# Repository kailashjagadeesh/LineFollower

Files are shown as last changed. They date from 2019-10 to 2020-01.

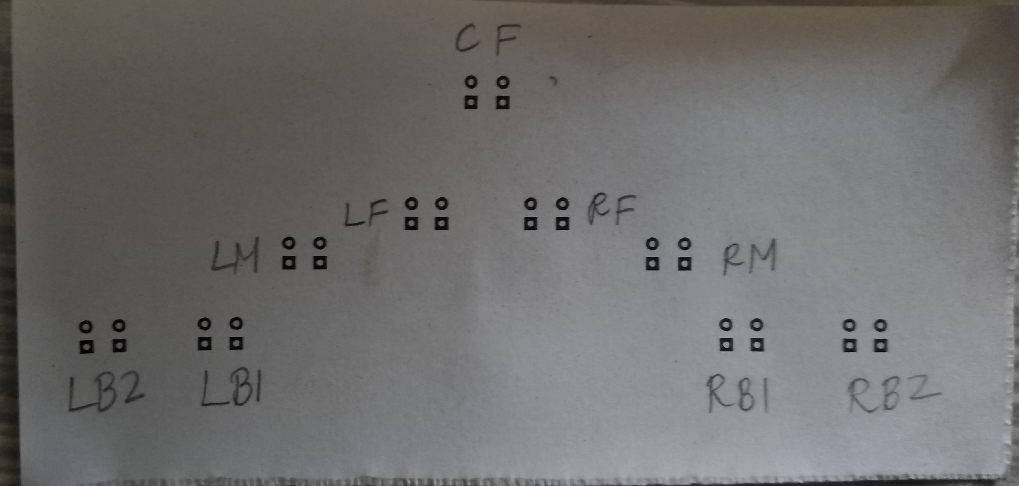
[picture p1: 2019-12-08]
Gen3/sensorNomenclature.jpg

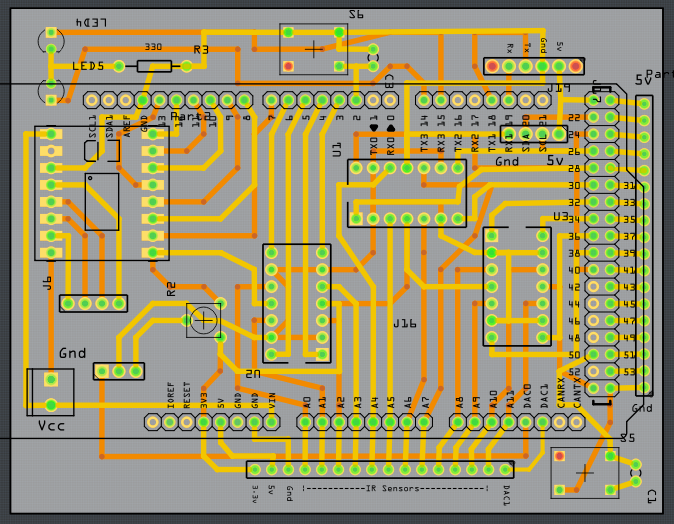
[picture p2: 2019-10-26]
Gen3/Designs/shieldPCB/PCB snip.png

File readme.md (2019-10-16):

# About
A general purpose differential-drive bot that can be used for various events.

# Code base tree
```
.
│── Gen1 : Meshmerize 2018 zonals, IITB TechFest
│   ├── actualrun
│   ├── Basic
│   │   ├── blackleft
│   │   ├── blackright
│   │   ├── whiteleft
│   │   └── whiteright
│   ├── calibration
│   ├── dryrun
│   ├── solving
│   ├── Today-Finals
│   ├── Track images
│   └── With EEPROM only
│       ├── BlackLeftEEPROM
│       ├── BlackRightEEPROM
│       ├── WhiteLeftEEPROM
│       └── WhiteRightEEPROM
├── Gen2 : Meshmerize 2019 zonals, IITB TechFest
│   ├── Meshmerizer
│   └── shortestPath
└── Gen3 : Meshmerize 2019 Finale, IITB TechFest
    └── Designs
        ├── sensorsPCB : 9 IR sensor PCB board with 3 control pins for controlling IR TX  
        └── shieldPCB
```

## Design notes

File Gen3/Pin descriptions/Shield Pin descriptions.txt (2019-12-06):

Motor Pins on MCU:

D12 - PWM A
D11 - AIN 2
D10 - AIN 1
D13 - STBY
D9 - BIN 1
D8 - BIN 2
D7 - PWM B

D6 - A0
D5 - A1
D4 - A2
D3 - A3
D40 - A4
D28 - A5
D30 - A6
D26 - A7
D32 - A8
D38 - A9
D34 - A10
D36 - A11

Bluetooth: 
TX-1 : TX
RX-1 : RX

Push buttons:
D2, D50

LEDs :
D15,D14

Ultrasonic slot Pins:

Trigger - D22
Echo - D24

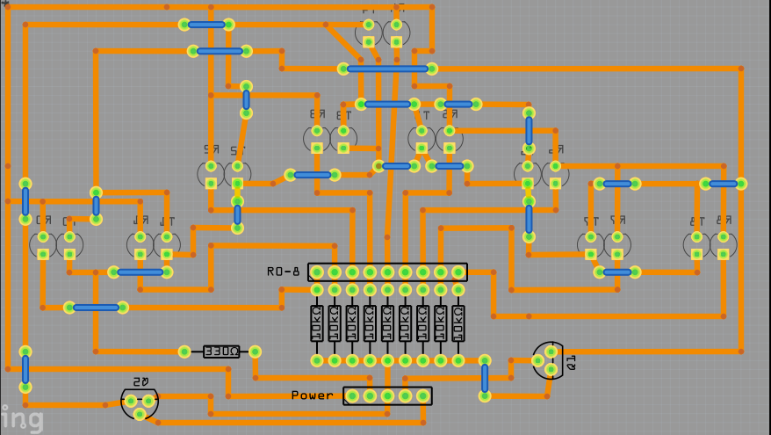
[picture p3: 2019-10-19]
Gen3/Designs/sensorsPCB/quick snap.png

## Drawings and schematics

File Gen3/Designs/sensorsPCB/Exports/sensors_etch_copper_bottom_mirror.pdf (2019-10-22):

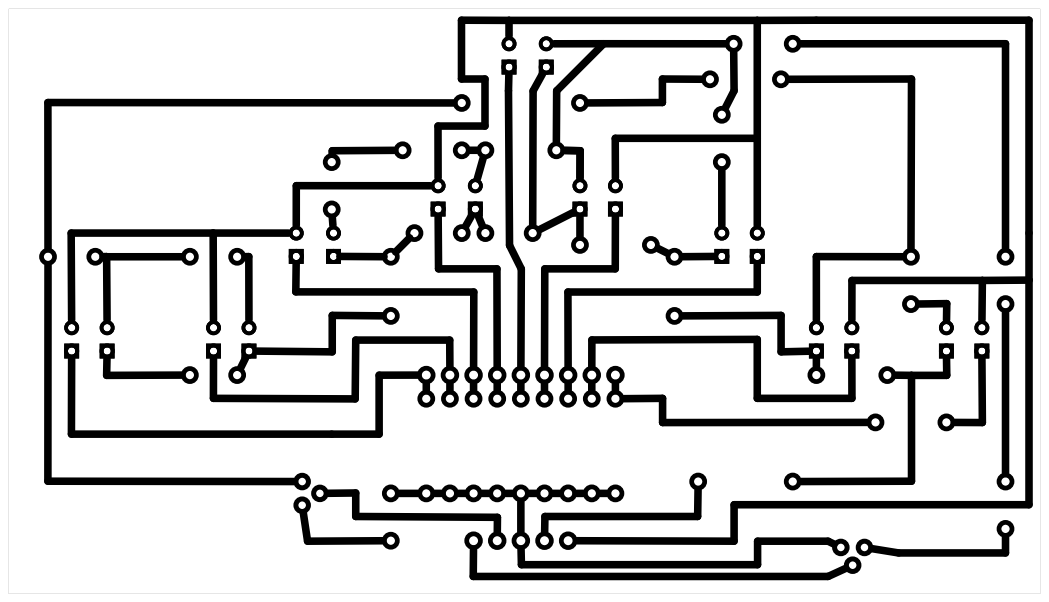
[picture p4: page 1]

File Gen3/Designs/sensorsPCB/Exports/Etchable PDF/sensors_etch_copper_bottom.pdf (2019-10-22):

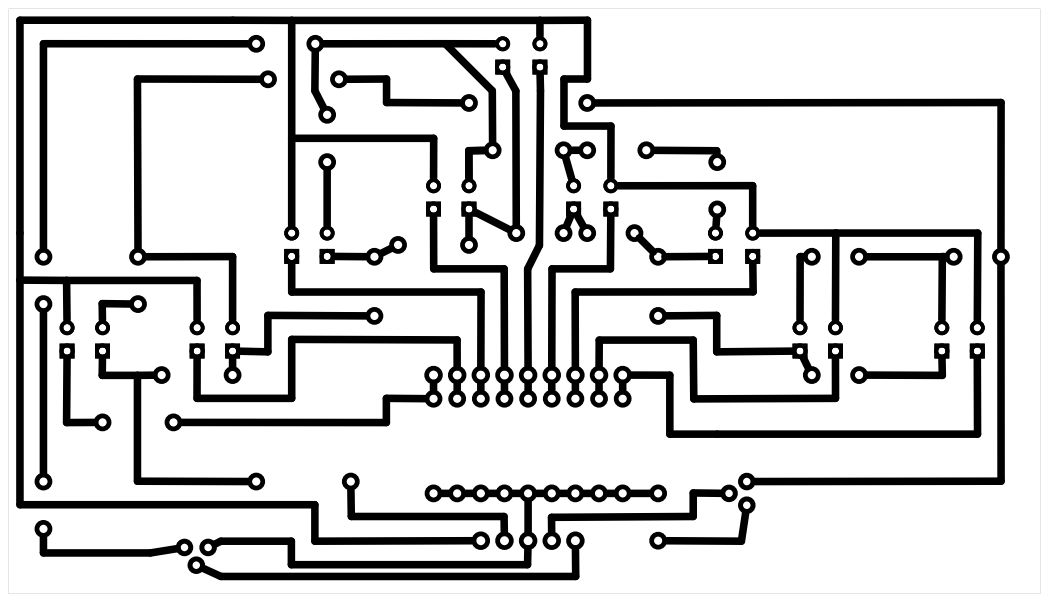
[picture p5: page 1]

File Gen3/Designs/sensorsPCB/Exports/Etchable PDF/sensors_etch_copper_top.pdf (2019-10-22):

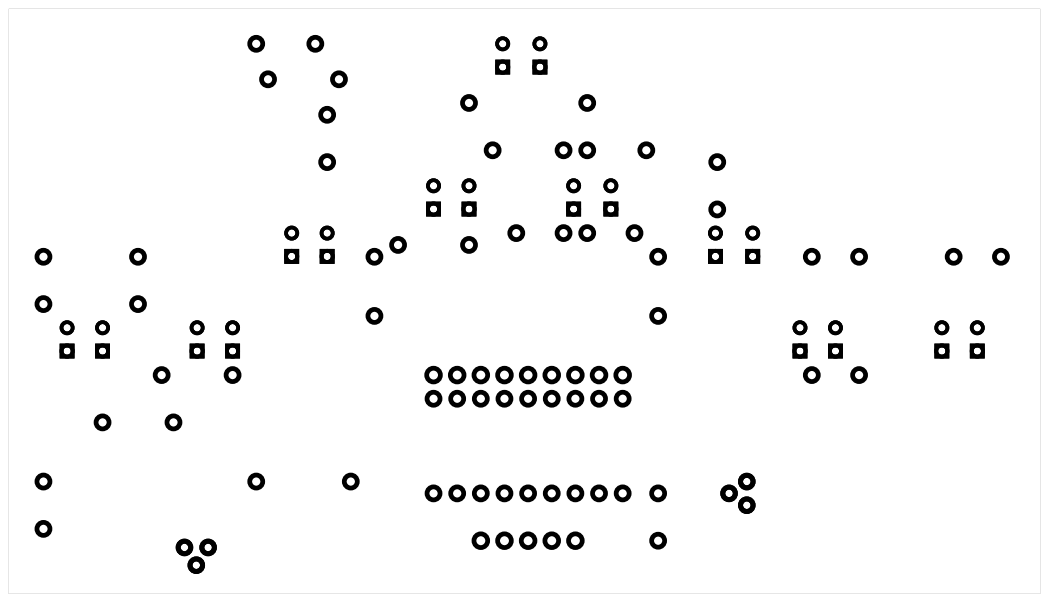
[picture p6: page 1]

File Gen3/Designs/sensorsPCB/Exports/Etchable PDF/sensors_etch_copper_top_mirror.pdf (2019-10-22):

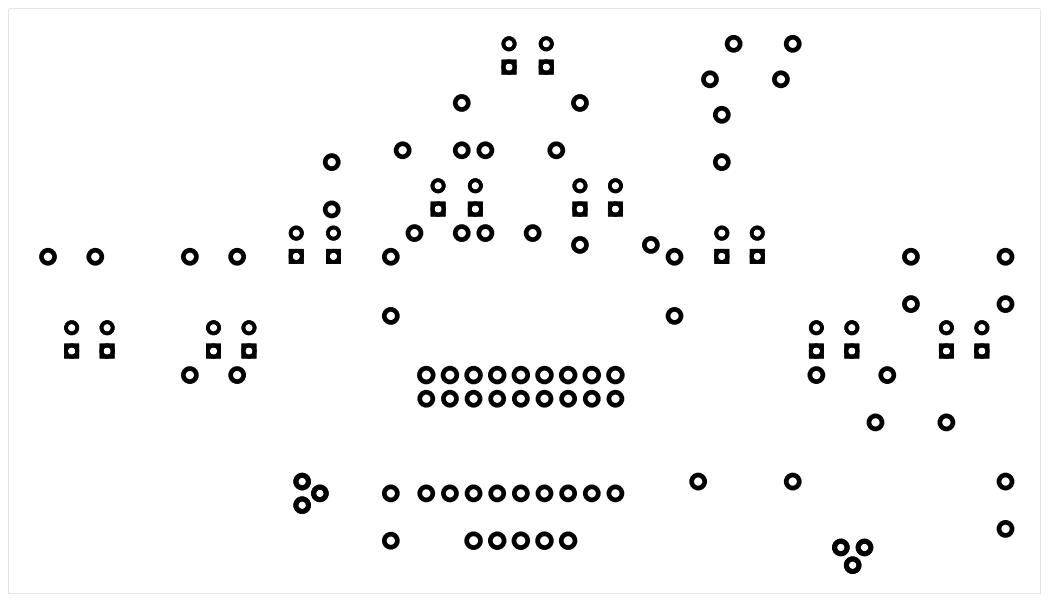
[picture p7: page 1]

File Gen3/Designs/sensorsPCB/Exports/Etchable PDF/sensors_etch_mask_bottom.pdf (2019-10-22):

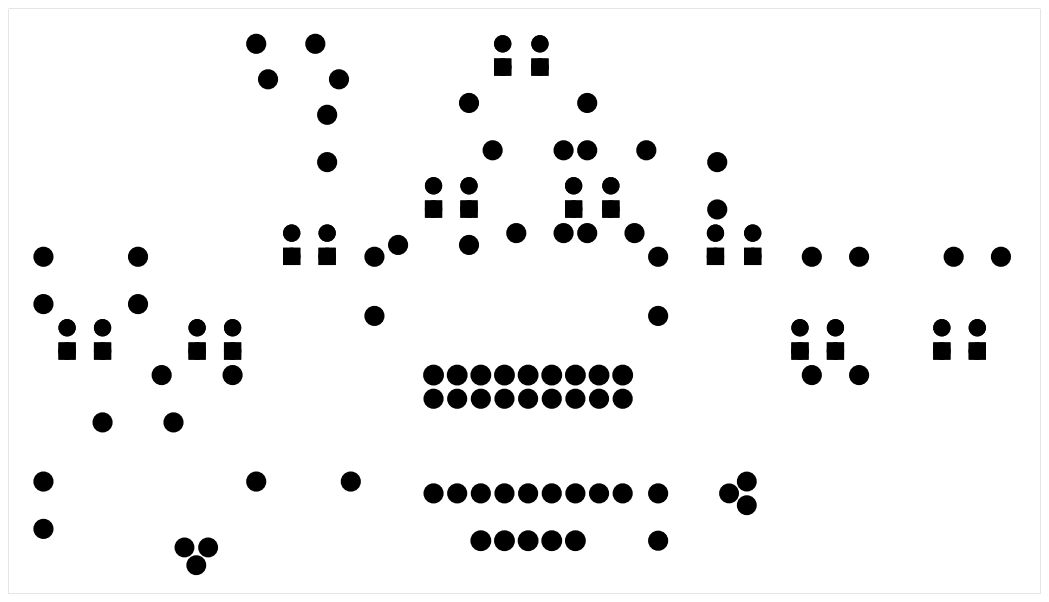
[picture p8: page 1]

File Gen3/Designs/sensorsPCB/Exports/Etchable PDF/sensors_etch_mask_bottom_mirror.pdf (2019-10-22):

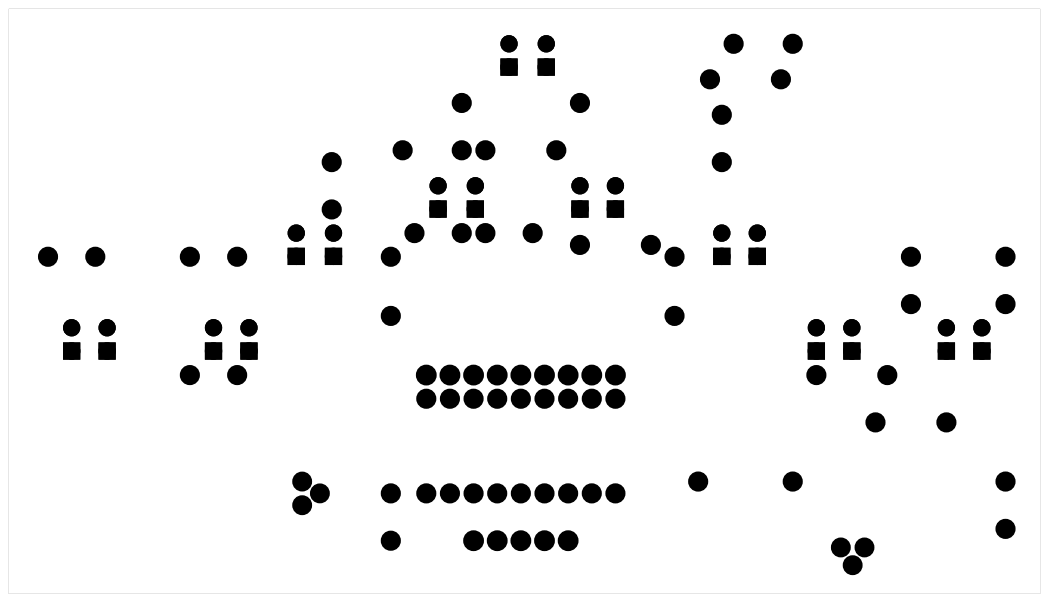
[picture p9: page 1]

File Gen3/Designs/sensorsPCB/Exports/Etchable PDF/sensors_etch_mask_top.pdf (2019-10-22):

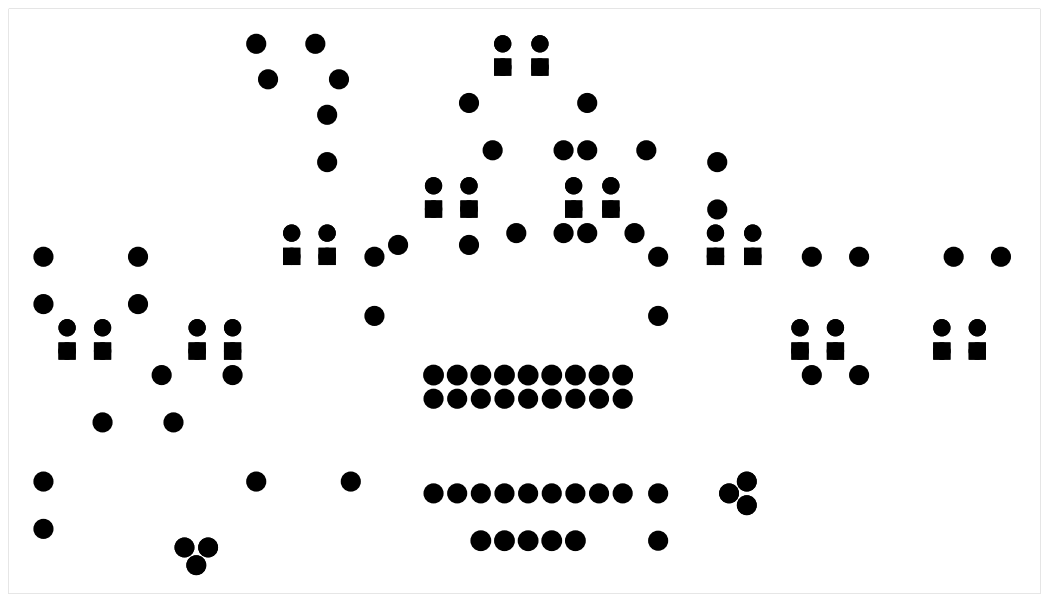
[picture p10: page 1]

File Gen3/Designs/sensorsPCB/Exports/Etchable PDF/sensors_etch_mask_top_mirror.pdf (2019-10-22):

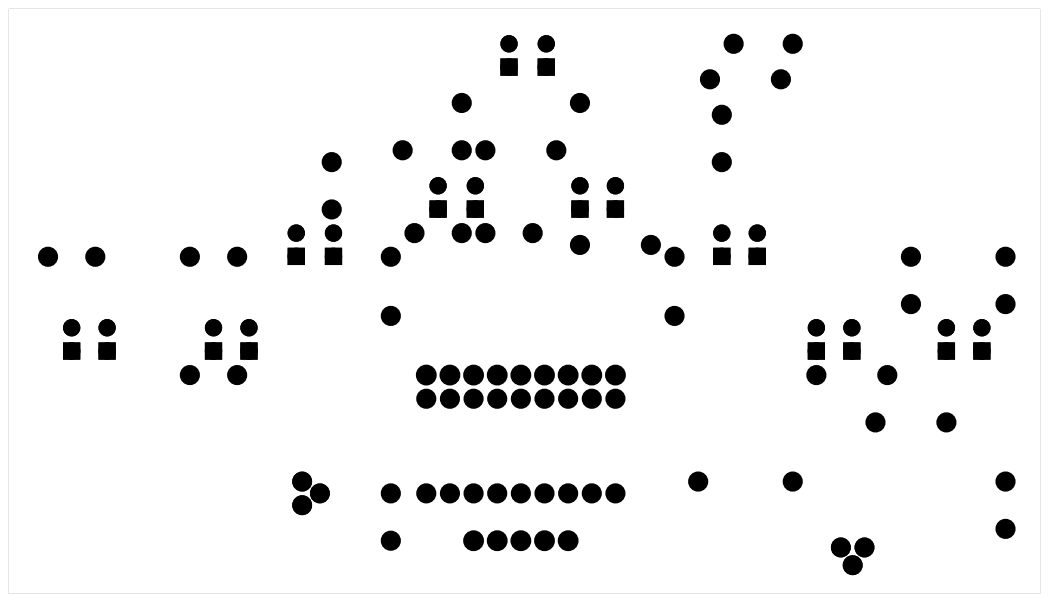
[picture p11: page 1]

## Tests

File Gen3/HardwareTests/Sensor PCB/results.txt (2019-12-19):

All sensors work nicely except for the middle sensor.
Concluded fault: the photodiode is probably faulty

--

analog value calibration

WHITE:
MAX VALUES:	389	348	352	350	9	454	313	417	365	
MIN VALUES:	378	340	345	344	7	447	307	410	359	
AVG VALUES:	383	344	348	347	8	450	310	413	362	

BLACK:
MAX VALUES:	67	73	104	314	8	419	259	114	70	
MIN VALUES:	65	71	102	309	6	412	254	111	69	
AVG VALUES:	66	72	103	311	7	415	256	112	69

Conclusions: Common DAC needs work, sensors have too much variations
Until DAC is fixed, using convertAnalogToDigital() as digitalreading

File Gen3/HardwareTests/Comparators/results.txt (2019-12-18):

Checking analog value results: 
    tested using Arduino Mega
    All ok!

Checking digital value results:
    tested using arduino Mega
    DAC is set to on-board 3.3V

    observation: OPAMPS outputs are 2.8~ when HIGH (Mega reads that as LOW)

    Therefore checking, voltage using multimeter and analog reads
    Result: 
        * All opamps get proper voltage for comparison
        * Outputs of opamps (3.3v comparison value)
            all ok!
            for 0v i/p, o/p = 0v
            for 5v i/p, o/p = 2.10v 

            The results were cross verified using analog reads at corresponding digital pins (using jumpers)
            approx 437 was read.

Results with Due:

pin 34 - not connected properly to the respective opamp o/p
pin 40 - not connected properly
pin 30

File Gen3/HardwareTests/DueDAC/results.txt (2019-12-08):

TESTING THE DAC OF THE DUE

It works, but now very accurate. (max of .4 V error was found) (with 8bit accuracy)

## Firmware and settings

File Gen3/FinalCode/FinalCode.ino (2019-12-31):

//dependencies
#include "src/BluetoothInterface/BluetoothInterface.h"
#include "src/SensorInterface/SensorInterface.h"
#include "src/PIDControl/PIDControl.h"
#include "src/TesterInterface/TesterInterface.h"
#include "src/MotorDriverInterface/MotorDriverInterface.h"
#include "src/LEDInterface/LEDInterface.h"
#include "src/JunctionControl/JunctionControl.h"
#include "src/configure.h"
#include "src/AsyncUltrasonic/AsyncUltrasonic.h"
#include "src/Twiddle/Twiddle.h"

//Bluetooth bluetooth;
Sensors sensors;
Motor motors;
MotorPIDControl pid(PID_IDEAL, 255, motors);
JunctionControl junctionControl(sensors, motors, pid);
volatile bool paused;


void setup()
{
    Debug::begin();
    Debug::useBluetooth();
    LED::init();
    paused = false;

    AsyncUltrasonic::init();
    AsyncUltrasonic::minimumDistance = ULTRASONIC_MIN_DISTANCE;

    Debug::println("Meshmerize Finale Winner!");

    Debug::println("Calibration");
    sensors.calibrate();
    motors.stopMotors();
    motors.setLeftDirection(Motor::FRONT);
    motors.setRightDirection(Motor::FRONT);
    
    while (1) {
        if (PushButtonInterface::read(1)) {
            junctionControl.setAlgorithm(LEFT_LOGIC);
            Debug::println("Using left major algorithm");
            break;
        }
        else if (PushButtonInterface::read(0)) {
            junctionControl.setAlgorithm(RIGHT_LOGIC);
            Debug::println("Using right major algorithm");
            break;
        }
        Debug::print(AsyncUltrasonic::distance);
        Debug::print(" | ");
        Debug::print((int)(AsyncUltrasonic::detectBlock()));
        Debug::print(" | ");
        sensors.updateAllSensors();
        sensors.printAllSensors();
        Debug::println("");

        AsyncUltrasonic::update();
    }

    delay(2000);

    Debug::println("Started");
}

void loop()
{
    AsyncUltrasonic::update();

    if (PushButtonInterface::read(0)) {
        //paused 
        LED::write(0, HIGH);
        Debug::println("---------------paused----------------");
        motors.stopMotors();
        delay(1000);
        while (!PushButtonInterface::read(0)) {
            if (PushButtonInterface::read(1)){
                junctionControl.removeJunction();
                LED::toggle(0);
                delay(500);
            }
        }
        delay(500);
        LED::write(0, LOW);
    }

    int16_t correction = pid.control(sensors.readLine());

    sensors.overshootControl();
    junctionControl.detect();

    motors.setLeftDirection(Motor::FRONT);
    motors.setRightDirection(Motor::FRONT);

    if (sensors.nSensorsOnLine <= 4)
        pid.setSpeedBasedOnCorrection(correction);
}

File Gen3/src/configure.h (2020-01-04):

#define WHITELINE_LOGIC
#define LED_PINS {14, 15}
#define PID_CONVFACTOR 100
#define NUM_PIDSENSORS 5
#define PID_IDEAL 2000

#define KP 8
#define KD 15
#define KI 0.1

#define KP2 17
#define KD2 8
#define KI2 0

#define PID_TUNING_ACCURACY 0.0001

#define ULTRASONIC_MIN_DISTANCE 14
#define ULTRASONIC_CLOSE_DISTANCE 5
#define BLOCK_REVERSE_DELAY 500

#define VERBOSE_DEBUG true

#define LED_PIN_RED 14

#define PID_THRESHOLD 14

#define MOTOR_EXCESS_TURN_SPEED 180
#define POST_JUNCTION_BASE_SPEED 180
#define MOTOR_OVERSHOOT_SPEED 150
#define MIN_OVERSHOOT_TIME 200
#define MIN_TURN_TIME 400

#define PAUSE_PUSHBUTTON 2

#define LAST_JUNCTION_THRESHOLD_TIME 500

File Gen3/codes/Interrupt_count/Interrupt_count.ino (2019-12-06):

#include <Grove_Motor_Driver_TB6612FNG.h>
#include <I2Cdev.h>

#include <TimerOne.h>

#define intr_count90 100;
volatile unsigned int counter_left = 0;
volatile unsigned int counter_right = 0;

 //Left Motor
int pwm_pin1 =10;
int dpin1 = 9; 
int dpin2 = 8;

//Right Motor
int pwm_pin2=5;
int dpin3= 7;
int dpin4= 6;

void docount_left()  // counts from the speed sensor for left motor
{
      counter_left++;
}
void docount_right() // counts from the speed sensor for right motor
{
      counter_right++;
}

void left_90()
{
 static int temp_count= counter_left;
    // Set left motor forward
  digitalWrite(dpin1, HIGH);
  digitalWrite(dpin2, LOW);
 
  // Set right motor reverse
  digitalWrite(dpin3, LOW);
  digitalWrite(dpin4, HIGH);
  if(temp_count < counter_left + intr_count90)
  {
    analogWrite(pwm_pin1,255);
    left_90();
  }
}

void right_90()
{
 static int temp_count= counter_right;
    // Set left motor reverse
  digitalWrite(dpin1, LOW);
  digitalWrite(dpin2, HIGH);
 
  // Set right motor forward
  digitalWrite(dpin3, HIGH);
  digitalWrite(dpin4, LOW);
  if(temp_count < counter_left + intr_count90)
  {
    analogWrite(pwm_pin2,255);
    right_90();
  }
}

void timerIsr()
{ 
  Timer1.detachInterrupt();  //stop the timer
  
  Serial.print("Left motor Interrupt count is:  ");
  Serial.println(left_counter, DEC); 

  
  Serial.print("Right motor Interrupt count is:  ");
  Serial.println(right_counter, DEC); 
   //enable the timer
   Timer1.attachInterrupt( timerIsr ); 
}

void setup()
{
  Serial.begin(9600);

  pinMode(pwm_pin1, OUTPUT);
  pinMode(dpin1, OUTPUT);
  pinMode(dpin2,OUTPUT);

  
  pinMode(pwm_pin2, OUTPUT);
  pinMode(dpin3, OUTPUT);
  pinMode(dpin4,OUTPUT);
  
  Timer1.initialize(1000000); // set timer for 1sec
  attachInterrupt(digitalPinToInterrupt(2), docount_left, RISING);  // increase counter when speed sensor pin goes High
  attachInterrupt(digitalPinToInterrupt(3), docount_right, RISING);  // increase counter when speed sensor pin goes High
  Timer1.attachInterrupt( timerIsr ); // enable the timer

  left_90();
  delay(1000);
  right_90();
}


void loop() {

}

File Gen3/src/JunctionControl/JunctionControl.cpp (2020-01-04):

#include "JunctionControl.h"

#include <Arduino.h>

#include "../TesterInterface/TesterInterface.h"
#include "../SensorInterface/SensorInterface.h"
#include "../PushButtonInterface/PushButtonInterface.h"
#include "../MotorDriverInterface/MotorDriverInterface.h"
#include "../LEDInterface/LEDInterface.h"
#include "../AsyncUltrasonic/AsyncUltrasonic.h"
#include "../configure.h"
#include "../Timer/Timer.h"

#ifndef ALGORITHM_LOGIC
#define ALGORITHM_LOGIC LEFT_LOGIC
#endif

#ifndef MOTOR_OVERSHOOT_SPEED
#define MOTOR_OVERSHOOT_SPEED 100
#endif

#ifndef MOTOR_TURN_SPEED
#define MOTOR_TURN_SPEED 0
#endif

#ifndef MOTOR_EXCESS_TURN_SPEED
#define MOTOR_EXCESS_TURN_SPEED 150
#endif

#ifndef MOTOR_JUNCTION_DELAY
#define MOTOR_JUNCTION_DELAY 500
#endif

#ifndef MIN_OVERSHOOT_TIME
#define MIN_OVERSHOOT_TIME 200
#endif

JunctionControl::JunctionControl(Sensors &_sensors, Motor &_motors, MotorPIDControl& _pid) : sensors(_sensors), motors(_motors), pid(_pid)
{
    backSensorState = 0;
    CFState = false;
    blockDetectFlag = false;
    mode = DRY_RUN;
    paused = 0;
    currentJunction = 0;
}

void JunctionControl::pause(uint32_t m) {
    paused = m + millis();
}

void JunctionControl::setAlgorithm(Algorithm algo) {
    algorithm  = algo;
}

void JunctionControl::addPathChoice(const char* choice) {
    strcat(path, choice);
    LED::toggle(1);
}

void JunctionControl::updateState()
{
    sensors.readSensors();
    sensors.convertAnalogToDigital();
    uint16_t sensorValues = sensors.digitalValues;

    VD(Debug::print("\nSensor: ");
    Debug::print((uint32_t)(sensorValues), 2);
    Debug::print("\tJunction: ");)

    backSensorState = sensorValues & (0b1111);
    backSensorState |= (sensorValues & (0b111100000)) >> 1;
    backSensorStateInverted = (backSensorState * 0x0202020202ULL & 0x010884422010ULL) % 1023; // Contains backSensorState's mirror inversion
    CFState = sensorValues & 0b000010000;

    blockDetectFlag =  AsyncUltrasonic::detectBlock();
}

void JunctionControl::detect()
{
    updateState();
    static uint16_t prevSensorValues = 0;
                      
    if (millis() > paused)
    if (blockDetectFlag == 1)
    {
        control(BL);
        blockDetectFlag = 0;
    }
    else if (millis() > paused) {
        if ((CFState == 0) && (backSensorState & 0b11) == 0b11 && (backSensorStateInverted & 0b11) == 0b11)
        {
            control(T);
        }
        // // Straight Right detection
        else if ((sensors.digitalValues & 0b000010011) == 0b000010011 
                    && (prevSensorValues & 0b000010011) == 0b000010011)
        {
            control(RS);
        }
        // // Straight Left detection
        else if ((sensors.digitalValues & 0b110010000) == 0b110010000 
                    && (prevSensorValues & 0b110010000) == 0b110010000)
        {
            control(LS);
        }
        // else if (sensors.digitalValues == 0b111001100 || sensors.digitalValues == 0b001100111) { //*
        //     control(T);
        // } 
        else if ((CFState == 0) && ((backSensorState & 0b11100010) == 0b11100010 )) {
            
            control(T);
        }
        else if((CFState==1) && ((backSensorState & 0b11000011) == 0b11000011)) {
            control(X);
        }
        else if ((CFState == 0) && ((backSensorStateInverted & 0b11100010) == 0b11100010 )) {
            control(T);
        }
        else if (sensors.digitalValues == 0b110000110 || sensors.digitalValues == 0b011000011) {
            control(T);
        }
        else if (sensors.digitalValues == 0b110001100 || sensors.digitalValues == 0b001100011) {
            control(T);
        }
        else if (sensors.digitalValues == 0b110001110 || sensors.digitalValues == 0b011100011) {
            control(T);
        }
        else if (sensors.digitalValues == 0b100000110 || sensors.digitalValues == 0b011000001) {
            control(T);
        }
        else if (sensors.digitalValues == 0b111001100 || sensors.digitalValues == 0b001100111) {
            control(T);
        }
        // //90 degree right
        else if ((CFState == 0) && (backSensorState == 3) )
        {
            control(R);
        }
        // //90 degrees left
        else if ((CFState == 0) && (backSensorStateInverted == 3) ) 
        {
            control(L);     
        }
        else if (sensors.digitalValues == 0b111000000 || sensors.digitalValues == 0b010000000) {
            control(L);
        }
        else if (sensors.digitalValues == 0b000000111 || sensors.digitalValues == 0b000000010) {
            control(R);
        }
        else if (backSensorState == 0b11111000 && CFState == 0) control(L);
        else if (backSensorStateInverted == 0b11111000 && CFState == 0) control(R);
        else if (CFState == 0 && backSensorState == 0) {
            control(END);
        }
    }

    prevSensorValues = sensors.digitalValues;
}
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

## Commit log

2019-09-06 Removed unnecessary folders, Added Sensors headerfile
2019-09-07 Removed errors (excluding QTRSensorAnalog)
    [Sensors.h]
2019-09-07 Initialized PID Control
2019-09-09 Implement PID logic
2019-09-09 fix some logical errors in Sensors.h
    [Sensors.h]
2019-09-14 Test sensors
2019-09-14 Update PID control code to match our code structure
2019-09-14 update pid header guard
2019-09-14 Test PID - write code
2019-09-14 Implement motor class
2019-09-14 Initialize testing code for PID
2019-09-15 Improved eeprom sensor values io
2019-09-17 Edited motor_control
2019-09-17 PID final code( not tuned)
2019-09-18 PID auto tuning added
2019-09-23 Edited PID tuning functions
2019-09-24 Tuned PID, reorganised files
2019-10-01 Added a filter path function
2019-10-01 Fixed X junction in Actual Run
    [Meshmerizer.ino]
2019-10-02 Added button control for choosing algorithm
2019-10-10 PCB design for shield
    [shieldPCB.fzz]
2019-10-12 Added motor driver and buck converter
    [shieldPCB.fzz]
2019-10-15 Connected 9 analog reads and motor driver
    [ShieldPCB.fzz, shieldPCB.fzz]
2019-10-15 reorganized code base
    [ShieldPCB.fzz]
2019-10-15 Designed sensor PCB
    [sensors.fzz]
2019-10-16 Exported PCB design, added a quick snap
2019-10-17 Added 2 layer pcb design
    [ShieldPCB.fzz, shieldPCB.fzz]
2019-10-18 Updated PCB design
    [shieldPCB.fzz]
2019-10-18 Updated Shield PCB
    [shieldPCB.fzz]
2019-10-18 Edited screenshot
    [shieldPCB.fzz]
2019-10-19 Updated new sensors design
    [sensors.fzz, shieldPCB.fzz]
2019-10-19 Add quick snap of the pcb design
2019-10-20 Code for motor speed
2019-10-22 Update exports
    [sensors.fzz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]
2019-10-22 Removed collisions in the pcb design
    [sensors.fzz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]
2019-10-22 fix thickness of connections
    [shieldPCB.fzz]
2019-10-23 Edited PCBs added gerber files
    [shieldPCB.fzz]
2019-10-26 Added silk screens
    [shieldPCB.fzz]
2019-10-26 Added code for interrupt count and motor speed
2019-12-05 Added Pin descriptions for motor
2019-12-05 Completed shield pin descriptions
2019-12-06 Button control and reset
2019-12-06 Implement SensorInterface (untested)
2019-12-06 Firing interrupts for White or Black line logic
2019-12-07 implement reSensors::adLine() fix: logic error @ Sensors::calibrate()
2019-12-07 Implement MotorDriverInterface Write test code for MotorDriverInterface
2019-12-07 Added SR and SL detection
    [sensors.fzz]
2019-12-08 Revert sensors fritziing file(bug)
    [sensors.fzz]
2019-12-08 Test Due - comparators: test failed for 2 pins
    [testcode.ino]
2019-12-08 tested motors
2019-12-08 Added interrupt functionality
2019-12-08 update SensorInterface
2019-12-08 90(L,R),180,360 degree turns tuned with Lipo
2019-12-09 Test Sensor PCB: test failed for the middle sensor concluded problem: the middle photodiode may be faulty
    [testcode.ino]
2019-12-09 fix: middle sensor not working replaced the photodiode all sensors work now
    [testcode.ino]
2019-12-12 Add test track
2019-12-13 Ultrasonic for block detection added along with test files
    [sensors.fzz]
2019-12-18 Implement conversion function for sensor values
2019-12-18 Generalise sensor reading logic to both black and white lines
2019-12-18 Implement LED interface
2019-12-18 Implement readLine() to be used with PID
2019-12-18 Generalize number of sensors used for PID
2019-12-18 Rewrite LEDInterface to incorporate more freedom
2019-12-19 Implement 2-step PID Control
2019-12-19 Ultrasonic sensor updates
2019-12-19 Extend bluetooth.print[ln] for float values
2019-12-19 Implement printing in binary values
2019-12-21 Fix code and change PID constants
2019-12-21 Implement Ultrasonic::calibrate
2019-12-21 Implement enable/disable feature for motors
2019-12-21 Improve Sensor calibration routine
2019-12-25 Try interrupts to handle overshoot
    [testcode.ino]
2019-12-26 Implement overshoot controller and junction detection
    [FinalCode.ino, testcode.ino]
2019-12-26 Fix first time LED usage
    [LEDInterface.cpp]
2019-12-26 Implement rear check fix mostly everything for dry run
    [FinalCode.ino, JunctionControl.cpp, PIDControl.cpp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]
2019-12-26 Implement async ultrasonic interface
2019-12-26 Added Timer library dependancy
2019-12-31 Improve ultrasonic readings
2019-12-31 Implement better queue system for overshoots Implement onboardcenterpin status read make debugging changes
    [SensorInterface.cpp]
2019-12-31 Implement secondary PID control after junction control
2019-12-31 Swap Push buttons
2019-12-31 Fix junction detections and control
    [FinalCode.ino, JunctionControl.cpp, configure.h]
2019-12-31 Fix white line detection
    [FinalCode.ino, SensorInterface.cpp, configure.h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]
2020-01-01 fix pid control for white lines
    [PIDControl.cpp, SensorInterface.cpp, test-refactor.ino]
